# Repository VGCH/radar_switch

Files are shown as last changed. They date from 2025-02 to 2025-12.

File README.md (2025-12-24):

# IoT Модуль управления освещением с радарным датчиком

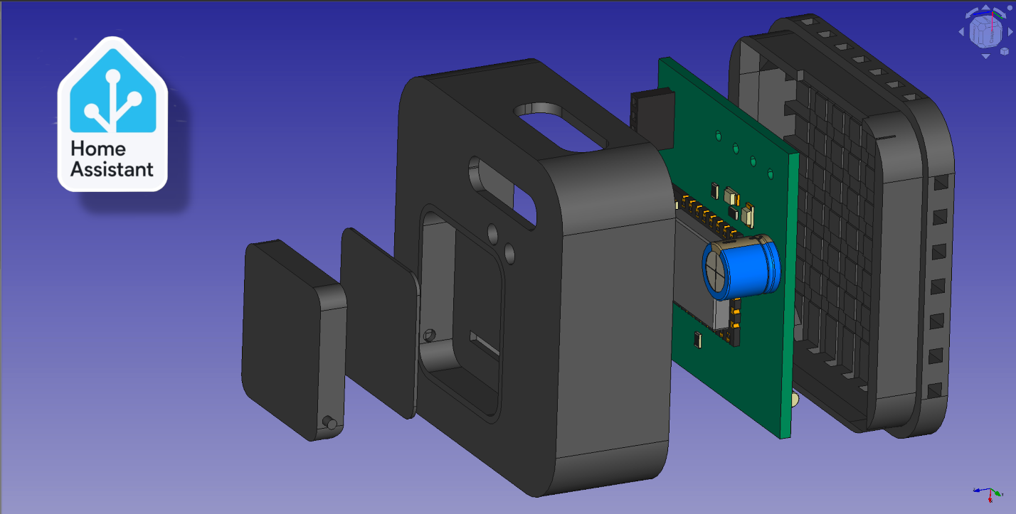
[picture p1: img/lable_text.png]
3D модель устройства


Работает как самостоятельное утройство, так и в составе умного дома Home Assistant:

В модуле реализованы следующие сервисы

> mDNS

> SSDP/UPnP

> Captive Portal

> MQTT Discovery

## Конфигурация устройства в Home Assistant:

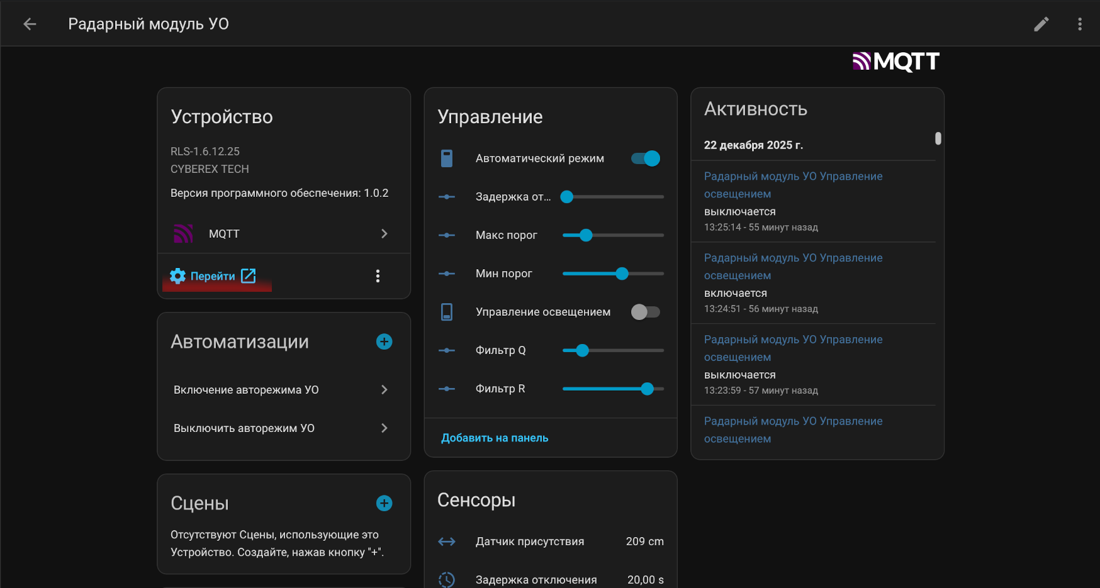
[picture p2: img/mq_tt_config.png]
Конфигурация устройства


## Веб-интерфейс:

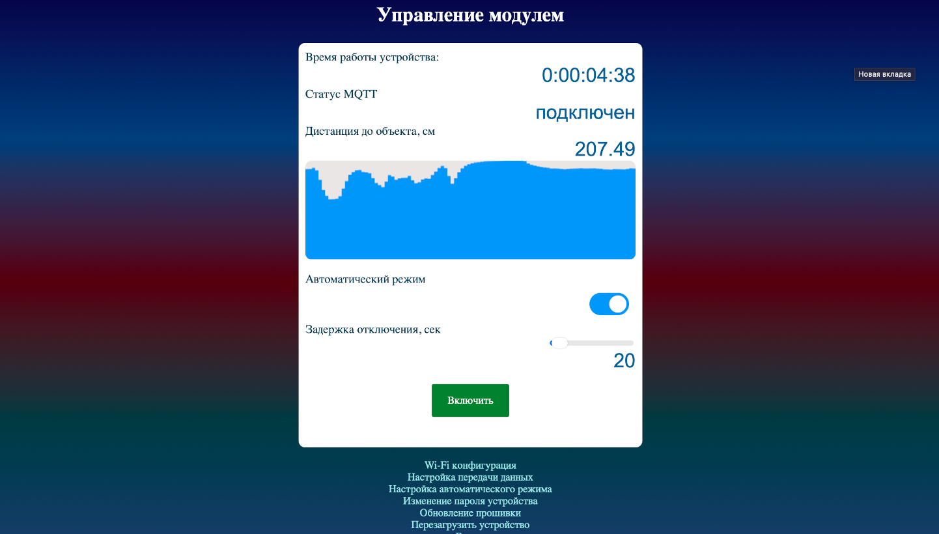
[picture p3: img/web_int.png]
Интерфейс


Репозиторий содержит исходники:

> Прошивки устройства

> Печатной платы

> Модели корпуса

## В веб-интерфейсе добавлен график для отображения дистанции в реальном времени:

Интерфейс

Полное описание в статье на Хабр

[Ссылка на статью ](https://habr.com/ru/articles/979262/)

[Поддержать донатом ](https://dalink.to/cyberex_tech)

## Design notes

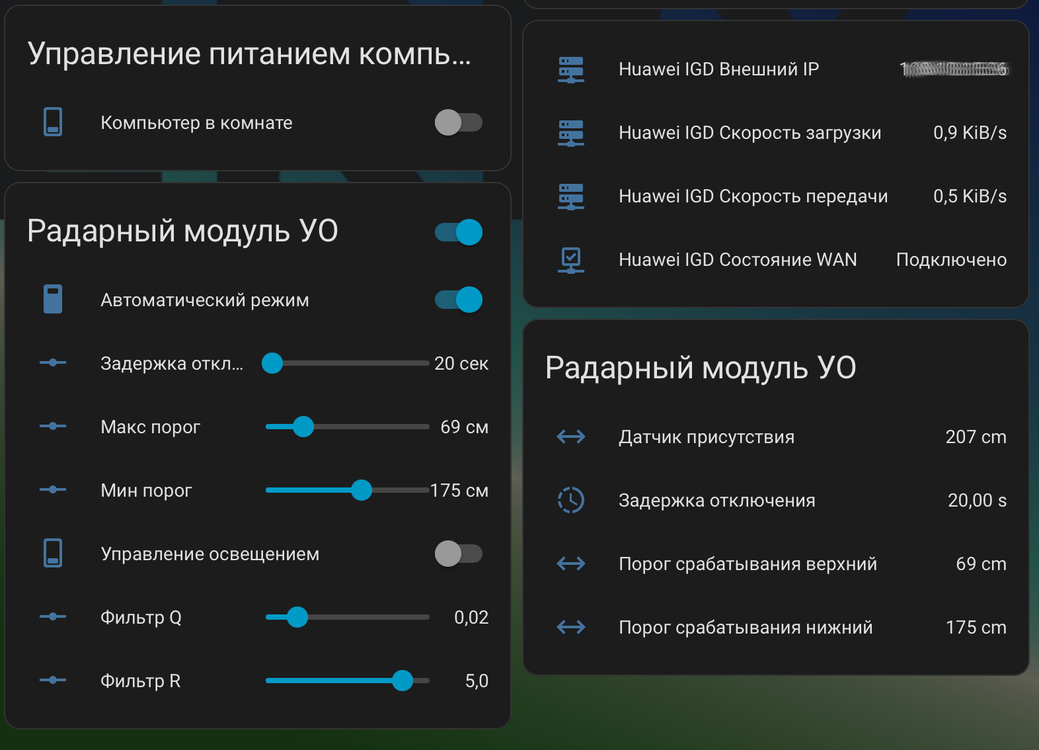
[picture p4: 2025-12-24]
img/ha_web.png

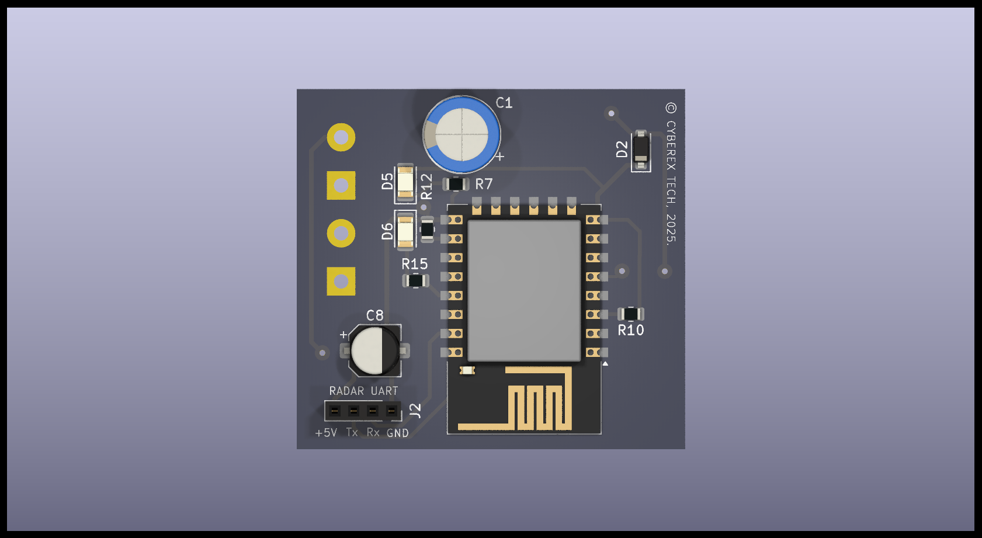
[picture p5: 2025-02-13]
RS_Board/RS_Board.png

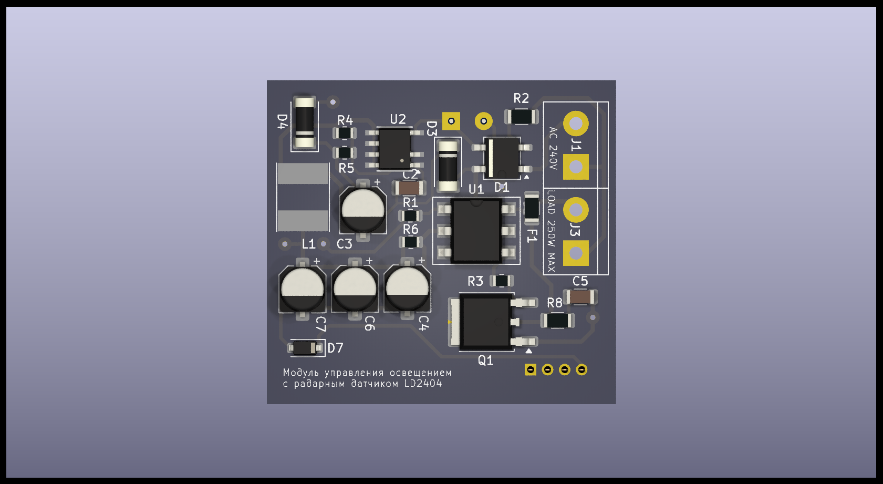
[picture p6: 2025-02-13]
RS_Board/RS_Board_a.png

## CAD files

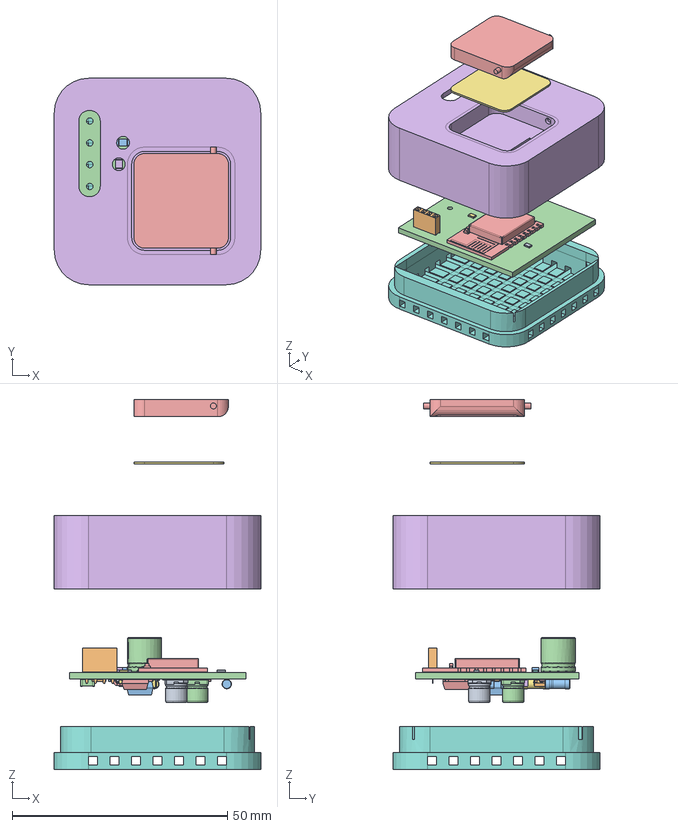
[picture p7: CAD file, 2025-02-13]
box/box_rs.FCStd
48.0 x 48.0 x 86.0 mm
R_0805_2012Metric
PinSocket_1x04_P2.00mm_Vertical
LED_1206_3216Metric
CP_Radial_D80mm_P380mm
ESP_12E001_cp
LED_1206_3216Metric002
R_0805_2012Metric002
R_0805_2012Metric004
R_0805_2012Metric006
R_1206_3216Metric
DIP_6_W762mm_SMDSocket
C_1206_3216Metric
CQ assembly
R_0805_2012Metric008
D_MELF_Standard
R_0805_2012Metric010
CP_Elec_5x54
R_0805_2012Metric012
R_1206_3216Metric002
CP_Elec_5x055
R_0805_2012Metric014
C_1206_3216Metric002
TO-269AA
R_0805_2012Metric016
R_1206_3216Metric004
PowerIntegrations_SO_8C
D_MELF_Standard001
RS_Board_PCB

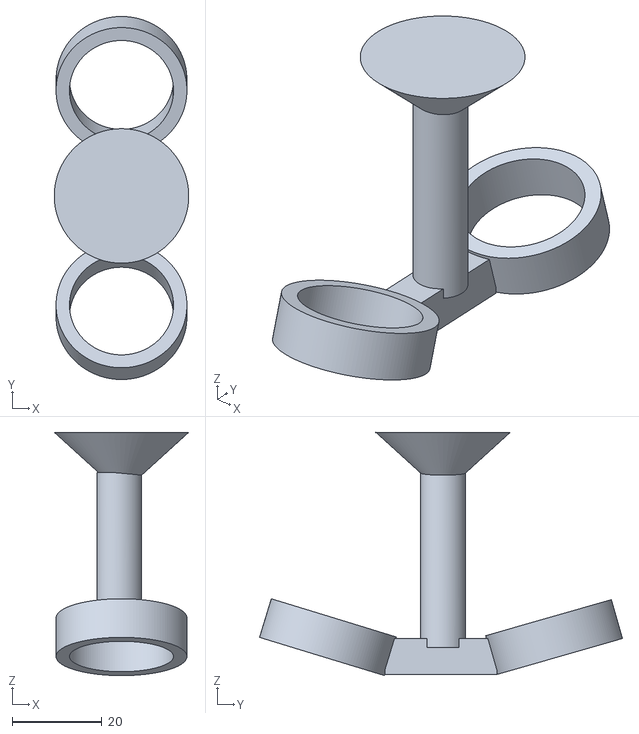
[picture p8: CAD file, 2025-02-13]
box/stl/держатель.stl
30.0 x 81.0 x 54.3

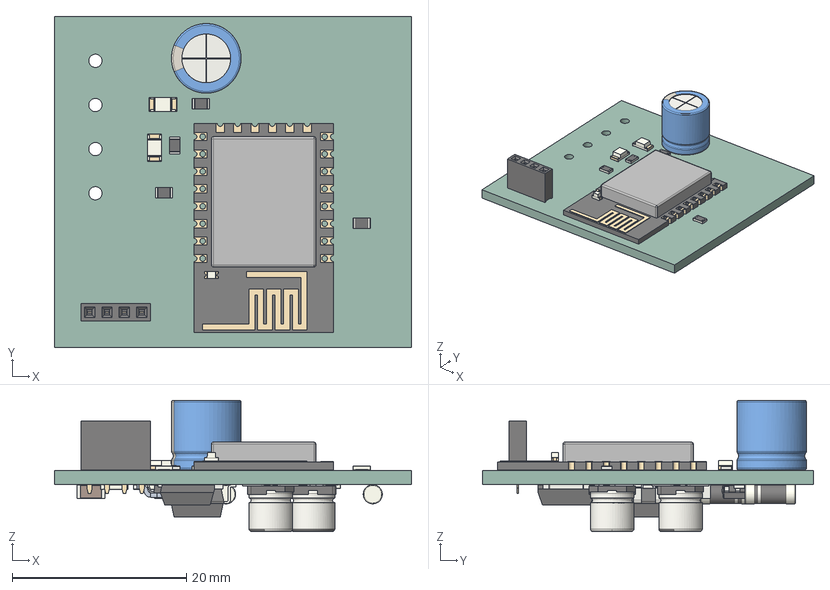
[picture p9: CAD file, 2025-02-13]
RS_Board/RS_Board.step
41.0 x 38.0 x 15.1 mm
R_0805_2012Metric x 9
PinSocket_1x04_P2.00mm_Vertical
LED_1206_3216Metric x 2
CP_Radial_D80mm_P380mm
ESP_12E001_cp
R_1206_3216Metric x 3
DIP_6_W762mm_SMDSocket
C_1206_3216Metric x 2
CQ assembly
D_MELF_Standard x 2
CP_Elec_5x54 x 2
TO-269AA
PowerIntegrations_SO_8C
RS_Board_PCB

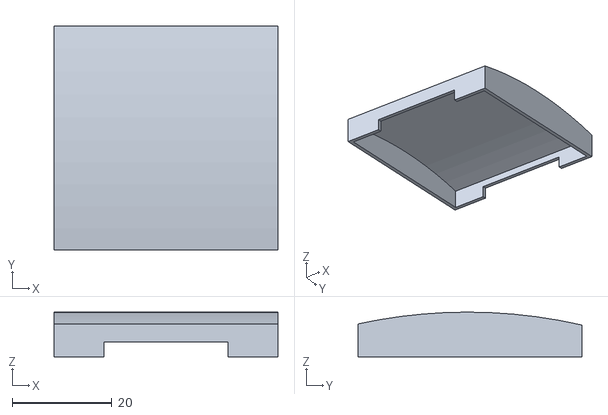
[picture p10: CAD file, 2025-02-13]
box/stl/заглушка.stl
45.0 x 45.0 x 9.00

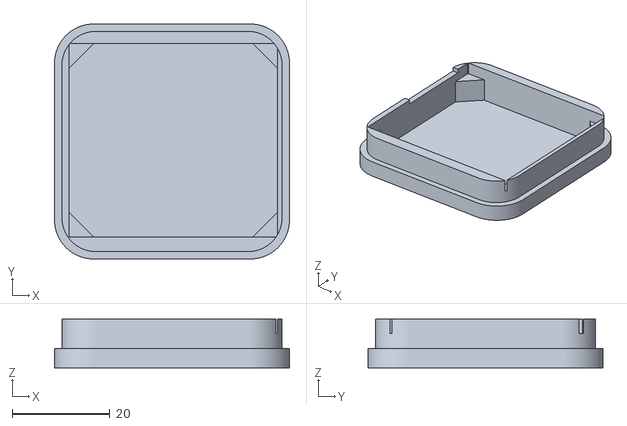
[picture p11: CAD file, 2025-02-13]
box/stl/box_rs-Cut005.stl
48.0 x 48.0 x 10.0

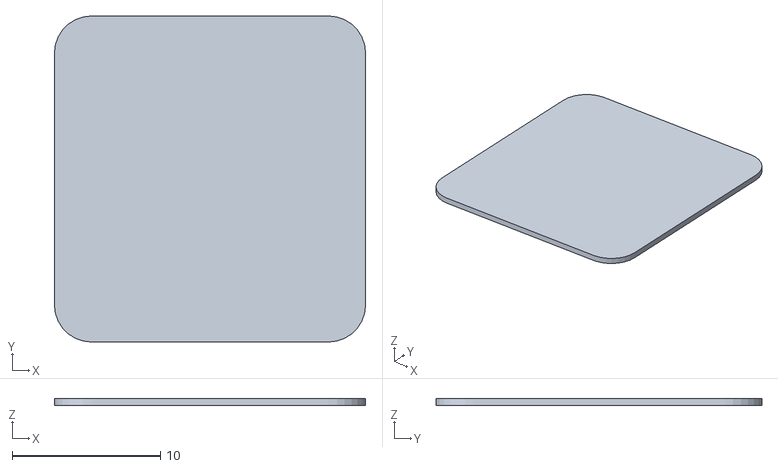
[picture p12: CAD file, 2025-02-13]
box/stl/box_rs-Fillet015.stl
21.0 x 22.0 x 0.5

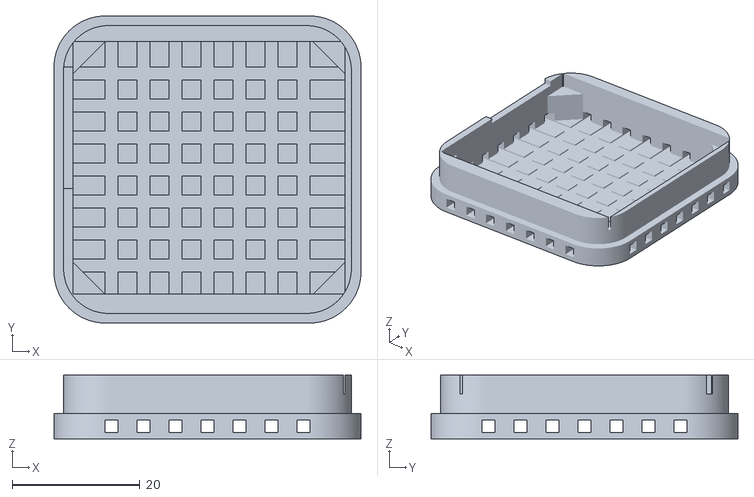
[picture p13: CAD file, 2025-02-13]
box/stl/box_rs-Cut017.stl
48.0 x 48.0 x 10.0

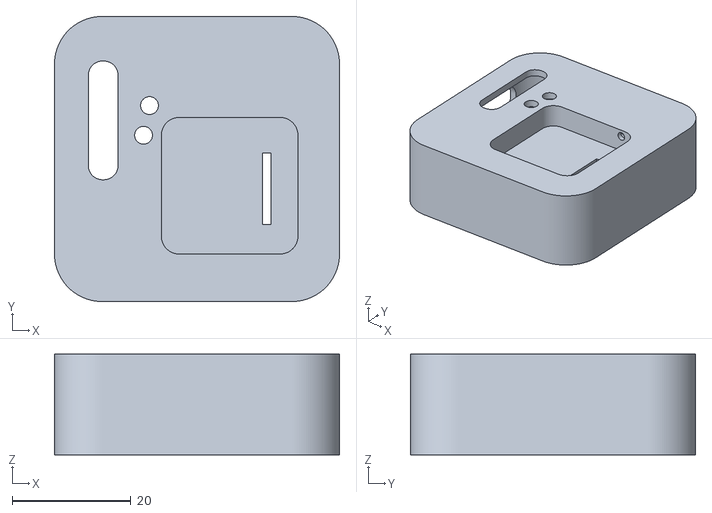
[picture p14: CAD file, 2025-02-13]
box/stl/box_rs-Cut014.stl
48.0 x 48.0 x 17.0

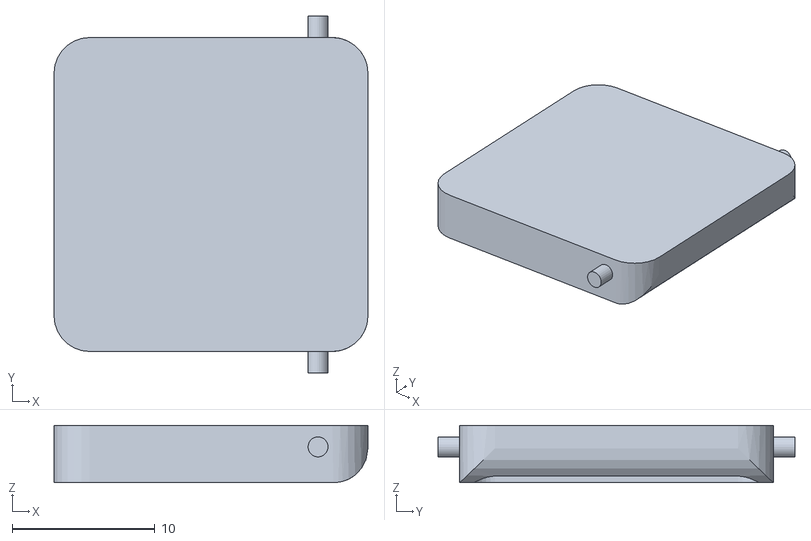
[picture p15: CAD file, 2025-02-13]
box/stl/box_rs-Common.stl
22.0 x 25.0 x 4.00

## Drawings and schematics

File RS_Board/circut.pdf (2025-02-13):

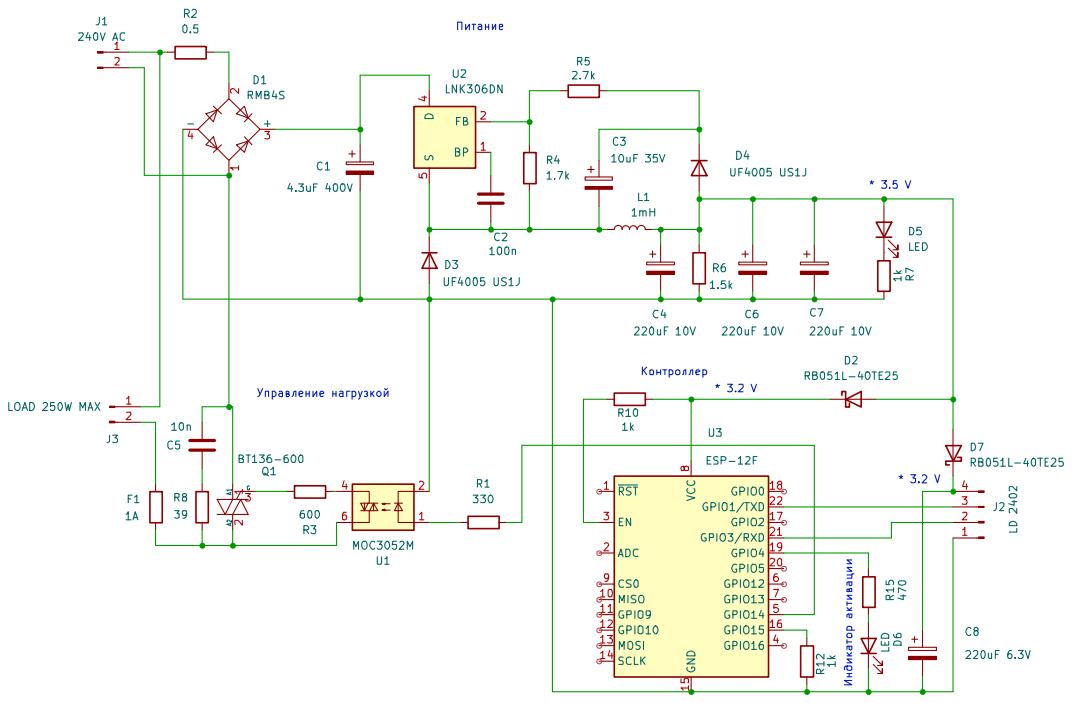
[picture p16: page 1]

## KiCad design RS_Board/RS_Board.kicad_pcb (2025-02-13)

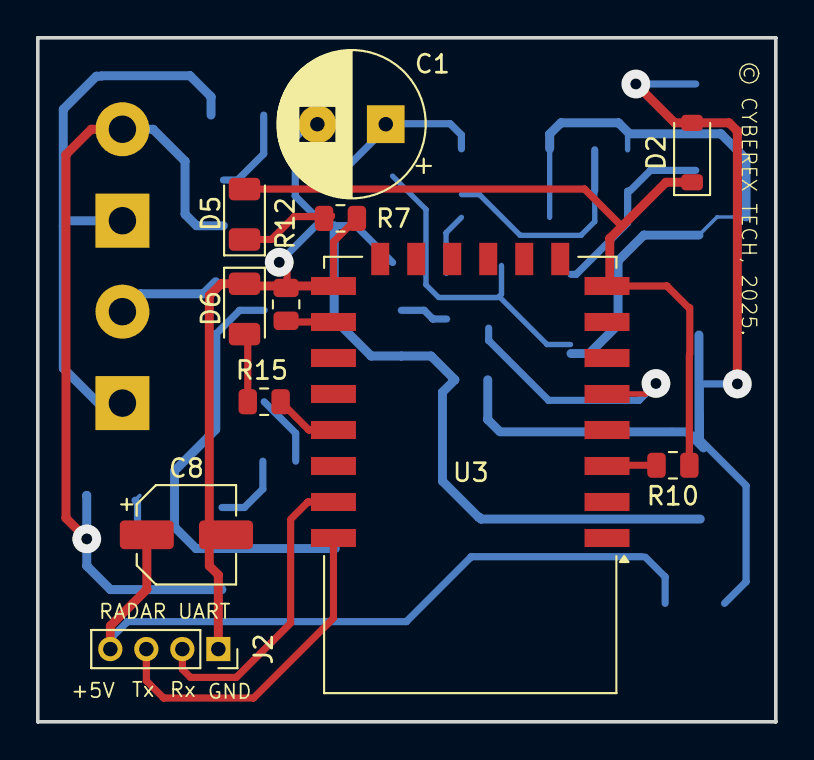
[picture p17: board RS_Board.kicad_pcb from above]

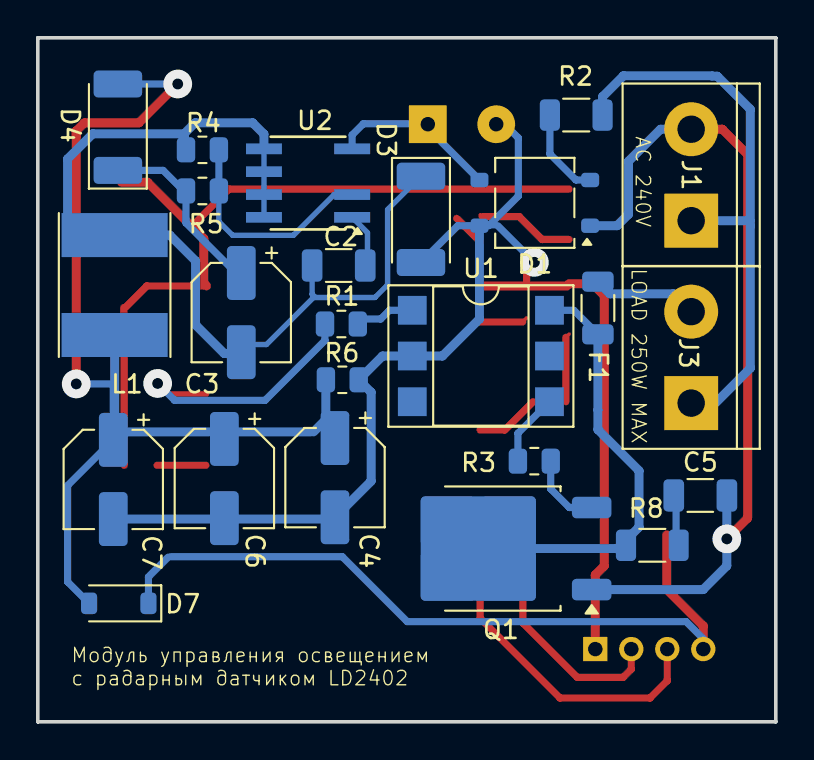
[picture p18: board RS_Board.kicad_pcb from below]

Board: 2 copper layers, 41.0 x 38.0 mm, 35 parts (24 on the bottom side), 26 nets.

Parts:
C1: 4.3uF 400V; CP_Radial_D8.0mm_P3.80mm
C2: 100n; C_1206_3216Metric
C3: 45uF 135V; CP_Elec_5x5.4
C4, C6, C7: 220uF 10V; CP_Elec_5x5.4
C5: 10n; C_1206_3216Metric
C8: 220uF 6.3V; CP_Elec_5x5.4
D1: RMB4S; TO-269AA
D2, D7: RB051L-40TE25; D_SOD-123
D3, D4: UF4005 US1J; D_MELF
D5, D6: LED; LED_1206_3216Metric
F1: 1А; R_1206_3216Metric
J1: 240V AC; TerminalBlock_bornier-2_P5.08mm
J2: LD 2402; PinSocket_1x04_P2.00mm_Vertical
J3: LOAD 250W MAX; TerminalBlock_bornier-2_P5.08mm
L1: 1mH; L_Taiyo-Yuden_NR-60xx_HandSoldering
Q1: BT136-600; TO-252-2
R1: 330; R_0805_2012Metric
R2: 0.5; R_1206_3216Metric
R3: 600; R_0805_2012Metric
R4: 1.7k; R_0805_2012Metric
R5: 2.7k; R_0805_2012Metric
R6: 1.5k; R_0805_2012Metric
R7, R10, R12: 1k; R_0805_2012Metric
R8: 39; R_1206_3216Metric
R15: 470; R_0805_2012Metric
U1: MOC3052M; DIP-6_W7.62mm_SMDSocket_SmallPads
U2: LNK362D; PowerIntegrations_SO-8C
U3: ESP-12F; ESP-12E

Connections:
unnamed: C5.1, R8.2
unnamed: C1.1, D1.3 (+), U2.4 (D)
unnamed: C1.2, C4.2, C6.2, C7.2, C8.2, D1.4 (-), D3.2 (A), D6.1 (K), J2.1, R6.2, R7.2, R12.2, U1.2, U3.15 (GND)
unnamed: D1.2, R2.2
unnamed: C4.1, C6.1, C7.1, D2.2 (A), D4.2 (A), D7.2 (A), L1.2, R6.1
unnamed: D2.1 (K), D5.2 (A), R10.2, U3.8 (VCC)
unnamed: C2.1, C3.2, D3.1 (K), L1.1, R4.2, U2.5 (S), U2.6 (S), U2.7 (S), U2.8 (S)
unnamed: C3.1, D4.1 (K), R5.2
unnamed: D5.1 (K), R7.1
unnamed: D6.2 (A), R15.2
unnamed: C8.1, D7.1 (K), J2.4
unnamed: J1.1, J3.1, R2.1
unnamed: C5.2, D1.1, J1.2, Q1.1 (A1)
unnamed: J2.2, U3.21 (GPIO3/RXD)
unnamed: J2.3, U3.22 (GPIO1/TXD)
unnamed: F1.2, J3.2
unnamed: F1.1, Q1.2 (A2), R8.1, U1.6
unnamed: Q1.3 (G), R3.2
unnamed: R1.1, U1.1
unnamed: R3.1, U1.4
unnamed: C2.2, U2.1 (BP)
unnamed: R4.1, R5.1, U2.2 (FB)
unnamed: R10.1, U3.3 (EN)
unnamed: R15.1, U3.19 (GPIO4)
unnamed: R1.2, U3.5 (GPIO14)
unnamed: R12.1, U3.16 (GPIO15)

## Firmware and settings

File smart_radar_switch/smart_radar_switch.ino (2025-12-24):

/* Радарный модуль управления освещением
 *  © CYBEREX Tech, 2025
 * 
 */

#include <ESP8266WiFi.h>
#include <WiFiClient.h>
#include <ESP8266WebServer.h>
#include <ESP8266HTTPUpdateServer.h>
#include <DNSServer.h>
#include <ESP8266mDNS.h>
#include <EEPROM.h>
#include <ESP8266SSDP.h>
#include <PubSubClient.h>
#include "const_js.h"
#include <ArduinoJson.h>

#define on_off_pin    14                    // Пин управления питанием
#define on_off_ind    4                     // Индикатор включения 


// WEBs
ESP8266WebServer server(80);
WiFiClient espClient;
PubSubClient client(espClient);
IPAddress apIP(10, 10, 20, 1);
IPAddress netMsk(255, 255, 255, 0);
ESP8266HTTPUpdateServer httpUpdater;

// DNS server
const byte             DNS_PORT = 53;
DNSServer              dnsServer;

// Текущий статус WLAN
unsigned int status = WL_IDLE_STATUS;

// Переменные для хранения статуса сетевого подключения
bool connect;
bool wi_fi_st;

bool stat_reboot, led_stat, stat_wifi, load_on, stat, annonce_mqtt_discovery; 

// Переменные используемые для CaptivePortal
const char *myHostname  = "Cyberex_SmartSw";            // Имя создаваемого хоста Cyberex_SmartSw.local 
const char *softAP_ssid = "CYBEREX-SmartSw";            // Имя создаваемой точки доступа Wi-Fi

String version_code = "RLS-1.6.12.25";

float distance = 0.0;
float auto_on_dist;
//timers
uint32_t low_t, med_t, prevMills, lastMsg, impOnDelay, reboot_t, lastConnectTry, auto_check_time;

String inputString = "";
bool off_status; 

int count_rf = 0;
int level_couts = 0;

// Глобальные переменные для фильтра Калмана
float R = 4.85;      // среднее отклонение (сила сглаживания)
float Q = 0.015;     // скорость реакции на изменение (подбирается вручную)
float Pc = 0.0;
float G = 0.0;
float P = 1.0;
float Xp = 0.0;
float Zp = 0.0;
float Xe = 0.0;

 // Структура для хранения токенов сессий 
struct Token {
    String value;
    long created;
    long lifetime;
};

Token   tokens[20];                    // Длина массива структур хранения токенов 

#define TOKEN_LIFETIME 6000000         // время жизни токена в секундах

#define MAX_STRING_LENGTH 30           // Максимальное количество символов для хранения в конфигурации


// Структура для хранения конфигурации устройства
struct {
     bool    mqtt_en;
     int     off_time;
     int     statteeprom; 
     int     counter_coeff;
     float   total;
     char    mySSID[MAX_STRING_LENGTH];
     char    myPW[MAX_STRING_LENGTH];
     char    mqtt_serv[MAX_STRING_LENGTH];
     char    mqtt_user[MAX_STRING_LENGTH];
     char    mqtt_passw[MAX_STRING_LENGTH];
     char    mqtt_topic[MAX_STRING_LENGTH];
     char    passwd[MAX_STRING_LENGTH]; 
     float   auto_off; 
     float   auto_on; 
     bool    auto_en;
     float   r_filter; 
     float   q_filter; 
  } settings;


String ch_id = String(ESP.getChipId());

void setup() {
    EEPROM.begin(sizeof(settings));                                 // Инициализация EEPROM в соответствии с размером структуры конфигурации      
    pinMode(on_off_pin, OUTPUT);
    pinMode(on_off_ind, OUTPUT);
    read_config();                                                  // Чтение конфигурации из EEPROM
    check_clean();                                                  // Провека на запуск устройства после первичной прошивки
   if(String(settings.passwd) == ""){   
                                                                    // Если  переменная settings.passwd пуста, то назначаем пароль по умолчанию
         strncpy(settings.passwd, "admin", MAX_STRING_LENGTH);
     }

     Serial.begin(115200);                                          // Инииализаия UART для полуения даннх с радара
     //Serial.println(settings.passwd);                                
     
     WiFi.mode(WIFI_STA);                                           // Выбираем режим клиента для сетевого подключения по Wi-Fi                
     WiFi.hostname("Smart Switch [CYBEREX TECH]");                     // Указываеем имя хоста, который будет отображаться в Wi-Fi роутере, при подключении устройства
     if(WiFi.status() != WL_CONNECTED) {                            // Инициализируем подключение, если устройство ещё не подключено к сети
           WiFi.begin(settings.mySSID, settings.myPW);
      }

     for(int x = 0; x < 160; x ++){                                  // Цикл ожидания подключения к сети (80 сек)
          if (WiFi.status() == WL_CONNECTED){ 
                stat_wifi = true;
                break;
           }
               delay(100); 
      
          }

     if(WiFi.status() != WL_CONNECTED) {                             // Если подключение не удалось, то запускаем режим точки доступа Wi-Fi для конфигурации устройства
            WiFi.mode(WIFI_AP_STA);
            WiFi.softAPConfig(apIP, apIP, netMsk);
            WiFi.softAP(softAP_ssid);
            stat_wifi = false;
        }
        
        delay(2000);
        // Запускаем DNS сервер
        dnsServer.setErrorReplyCode(DNSReplyCode::NoError);
        dnsServer.start(DNS_PORT, "*", apIP);
        // WEB страницы
        server.on("/", page_process);
        server.on("/login", handleLogin);
        server.on("/script.js", reboot_devsend);
        server.on("/style.css", css);
        server.on("/index.html", HTTP_GET, [](){
        server.send(200, "text/plain", "Radar Smart Switch"); });
        server.on("/description.xml", HTTP_GET, [](){SSDP.schema(server.client());});
        server.on("/inline", []() {
        server.send(200, "text/plain", "this works without need of authentification");
        });
        server.onNotFound(handleNotFound);
        // Здесь список заголовков для записи
        const char * headerkeys[] = {"User-Agent", "Cookie"} ;
        size_t headerkeyssize = sizeof(headerkeys) / sizeof(char*);
        // Запускаем на сервере отслеживание заголовков 
        server.collectHeaders(headerkeys, headerkeyssize);
        server.begin();
        connect = strlen(settings.mySSID) > 0;                                            // Статус подключения к Wi-Fi сети, если есть имя сети
        SSDP_init();
        // Устанавливаем значения переменных R и Q фильтра из памяти
        if (!isnan(settings.r_filter)) { // Проверка на пустоту в памяти
            R = settings.r_filter;
         }

        if (!isnan(settings.q_filter)) { // Проверка на пустоту в памяти
            Q = settings.q_filter;
         } 
        if (isnan(settings.off_time)) { // Проверка на пустоту в памяти
            settings.off_time = 10;
         } 
                     
}

void loop() {
        portals();
        dnsServer.processNextRequest();
        server.handleClient();  
        reboot_dev_delay();
        MQTT_send(); 
        auto_process();
        radar_process();
}

void reboot_devsend(){
     String input = server.arg("script");         // Js скрипт процессинг
       if (input == "reb_d"){
               server.send(200, "text", FPSTR(reb_d));
         }else if(input == "config_js"){
               server.send(200, "text", FPSTR(config_js));
         }else if(input == "aconf_js"){
               server.send(200, "text", FPSTR(aconf_js));
         }else if(input == "update_js"){
               server.send(200, "text", FPSTR(update_js));
         }else if(input == "pass_js"){
               server.send(200, "text", FPSTR(pass_js));
         }else if(input == "js_wifi"){
               server.send(200, "text", FPSTR(js_wifi));
         }
}

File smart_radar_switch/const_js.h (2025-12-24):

const char reb_d[] PROGMEM = R"rawliteral(
   function rebootdev() {
        modal.style.display = "block";
     }
   var t = 60;
   var time = document.getElementsByClassName("clock")[0];
     function fun() {
         t--;
        time.innerHTML = "<b>Оставшееся время: "+ t +" сек.</b>"
       if(t <= 0) {
         location.href = "/";
         clearInterval(inter);
       }
   }
   
  function rebootdev_s() {
      var msg = document.getElementsByClassName("modal-body")[0];
      var req5 = new XMLHttpRequest();
            req5.open('GET','/?page=dev_reboot');
            req5.onreadystatechange = function(){
              if (req5.readyState === 4 && req5.status === 200) {
                     msg.innerHTML ="<br><b>Выполняется перезапуск устройства...</b><br>"
                     var inter = setInterval("fun()", 1000);
              }
            }
        req5.send();
}
//  График
        const ctx = document.getElementById('graphic').getContext('2d');
        const data_g = new Array(100).fill(0); // 100 значений сразу
        let counter = 0;

        function draw() {
            ctx.clearRect(0, 0, 500, 150);
            
            // Всегда 100 столбцов
            for (let i = 0; i < 100; i++) {
                const maxVal = Math.max(...data_g);
                const scale = maxVal ? 150 / maxVal : 1;
                const height = data_g[i] * scale;
                
                ctx.fillStyle = '#2196F3';
                ctx.fillRect(i * 5, 150 - height, 5, height);
            }
        }

// Отрисовываем сразу
draw();

// js
       setInterval(server_time, 1000);
       var last_st = "";
       var last_st2 = "";
      function server_time(){
         var worktime = new XMLHttpRequest();
             worktime.open("GET","?page=time",true);
             worktime.onreadystatechange = function(){
          if (worktime.readyState === 4 && worktime.status === 200) {
                const obj = JSON.parse(worktime.responseText);
                document.getElementById("timew").innerHTML      = obj.time;
                document.getElementById("distance").innerHTML   = obj.distance;
                data_g.shift(); // Удаляем самый старый (слева)
                // добавляем данные в график
                data_g.push(Number(obj.distance)); // Новое значение добавляется в конец
                draw(); // Отрисуем график
                if(last_st !== obj.chanel1){
                   last_st = obj.chanel1;
                   if(obj.chanel1 === "On"){
                      document.getElementById("pbut").innerHTML = "<center><a href=\"#\" class=\"btn_on\" onclick=\"on_off()\">Выключить</a></center>";
                   }else{
                      document.getElementById("pbut").innerHTML = "<center><a href=\"#\" class=\"btn_off\" onclick=\"on_off()\">Включить</a></center>";
                   }
                 }
                   if(last_st2 !== obj.auto_st){
                    last_st2 = obj.auto_st;
                    document.getElementById("pbsw").innerHTML = "<label class=\"switch\"><input onclick=\"switch_b(this.checked ? 'on' : 'off')\" type=\"checkbox\" id=\"switch_auto\" "+obj.auto_st+" ><span class=\"slider round\"></span></div></label>";
                 }
                }
              }
             worktime.send();
           }
         
      function on_off(){
         var power = new XMLHttpRequest();
             power.open("GET","?page=power",true);
             power.onreadystatechange = function(){
          if (power.readyState === 4 && power.status === 200) {
                var data = power.responseText;
                var myArray = data.split("0");
                document.getElementById("pbut").innerHTML    = myArray[0];
                //document.getElementById("radios").innerHTML  = myArray[1];
                 }
              }
             document.getElementById("pbut").innerHTML  = "<center>Секундочку...</center>";
             power.send();
           }
       
      function switch_b(radio){
            var value = radio;
              var xhr = new XMLHttpRequest();
                  xhr.open('POST', '?page=indata', true);
                  xhr.setRequestHeader('Content-type', 'application/x-www-form-urlencoded');
                  xhr.onreadystatechange = function() {
                   if (xhr.readyState === 4 && xhr.status === 200) {
                          console.log('Данные успешно отправлены на сервер' + value);
                        }
                    };
                  xhr.send('switch_auto=' + value);
                }
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
